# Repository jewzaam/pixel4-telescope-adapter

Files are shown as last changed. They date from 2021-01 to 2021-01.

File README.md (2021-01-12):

# Overview

This is a set of models to take pictures using a Pixel 4 phone when using an eyepiece adapter.  For example, I use a 2" to 1.25" adapter to fit 1.25" eyepieces to my 8" Dobsonian (Orion SkyQuest XT8).  This project replaces the 2" to 1.25" adapter with a tube that a custom Pixel 4 case can attach onto.

## You will need...

- access to a 3D printer
- enough plastics to print with
- 3x hex bolts of short length
- 1x hex bolt of longer length

## OpenSCAD

Some conventions I use are docuemted in my [openscad-library](https://github.com/jewzaam/openscad-library) repo along with some tools I find useful for debugging, building shapes, etc for this and other projects.  This project has no direct dependencies on other projects at this time, NO external libraries needed!!

All OpenSCAD input parameters are prefixed with `input_` and have initial values of what I used for my first full print.  For that I selected:
- short hex bolts: M4-0.7 x 10mm
- long hex bolt: M4-0.7 x 25mm
- eyepiece adapter height: 35mm
- eyepiece outer diameter: 56mm
- case adapter height: 35mm
- case inner diameter: 57mm

# Building the Adapter

## Knurled Bolts

The bolts I got are not easily turned by hand so I printed knurled caps:
- eyepiece adapter: [scad](src/knurled-hex-cap.scad), [stl](stl/m4-knurled-cap-shallow.stl), [thingieverse]()
- case adapter: [scad](src/knurled-hex-cap.scad), [stl](stl/m4-knurled-cap.stl), [thingieverse](https://www.thingiverse.com/thing:4716337)

Note on the diameter of the cap, make sure it will not be big enough to interfer with the camera adapater.  If it's too wide you can't push the camera adapter all the way down on the eyepiece adapter due to hitting the knurled cap for holding the 1.25" eyepiece.  Also you can do differenet diameters if that is what you want.  I went simple, same for everything.

I did these in a bright color I could easily see on a dark night.  If I get some glow in the dark filiment again maybe that would be better...

No support required.

A center hole punch and a hole drilled in a bit of wood were used to gently drive the bolt into the cap.

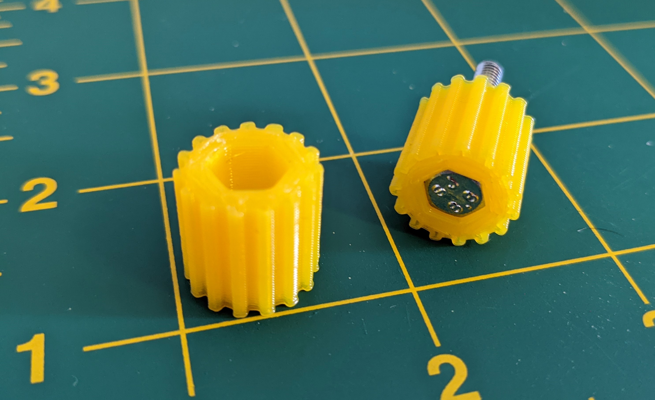
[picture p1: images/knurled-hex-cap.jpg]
Knurled Cap


## Eyepiece Adapter

A simple print that does require support.  Recommend printing in the orientation given.  You want to surface the 1.25" eyepiece rests on (inside the tube) to be smooth.  You also want the print to be tight.  You can sand it down.  This ensures you have a solid basis for the whole system.  Note there isn't anything specific to the Pixel 4 in this print!  If you have a different phone you could spend the time to create a case for it and use this adapter.

At the top of the [scad](src/telescope-eyepiece-adapter-with-extension.scad) you'll find a writeup on why I selected the values I selected.  If you're looking at your eyepieces and wondering what you need to print this may help.

Print with supports.  Select a pretty good in-fill.  I did 50% and it's solid.

After printing use your long knurled bolt to "cut" threads in the hole.

Files: [scad](src/telescope-eyepiece-adapter-with-extension.scad), [stl](stl/eyepiece-adapter-35mm.stl), [thingieverse]()

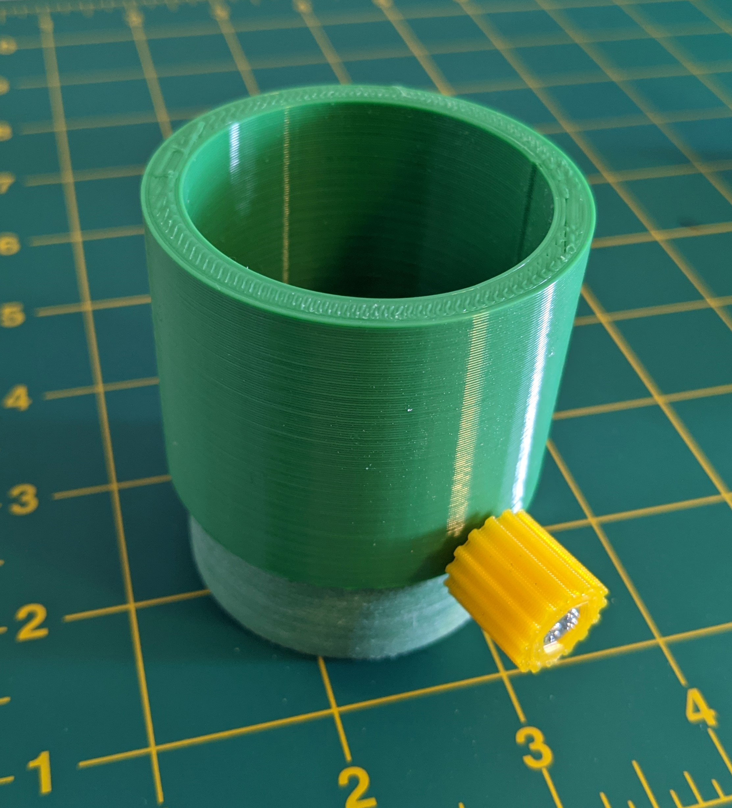
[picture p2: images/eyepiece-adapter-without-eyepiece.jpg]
Eyepiece Adapter without Eyepiece


This will be used to hold your 1.25" eyepiece in the adapter.

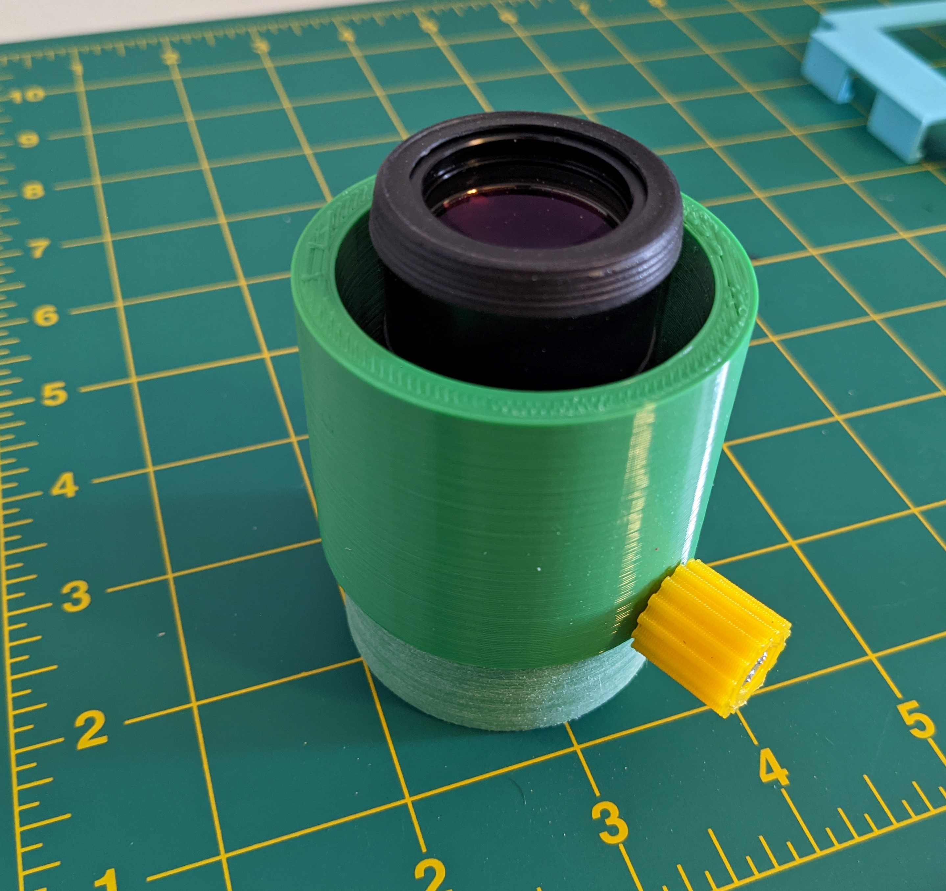
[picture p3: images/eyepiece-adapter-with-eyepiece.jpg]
Eyepiece Adapter with Eyepiece


## Pixel 4 Adapter

The phone adapter is printed attached to a phone case.  It attaches to the eyepiece adapter by screwing down 3 short bolts you created earlier.  This allows some small adjustments in where the camera.  Early prototypes tried to rely on friction of pieces only but there were two key problems.  First I found it hard to nail down the tolerances, so prints were never quite the right diameters.  Second when I did get it right the weight of the phone on the case could cause things to misalign.

Print with supports.  Select a pretty good in-fill.  I did 50% and it's solid. (Yes, this is the same as the eyepiece adapter.)

After printing use the short knurled bolst to "cut" threads in each of the 3 holes.

Files: [scad](src/pixel4-eyepiece-adapter.scad), [stl](stl/pixel4-eyepiece-adapter-35mm.stl), [thingieverse]()

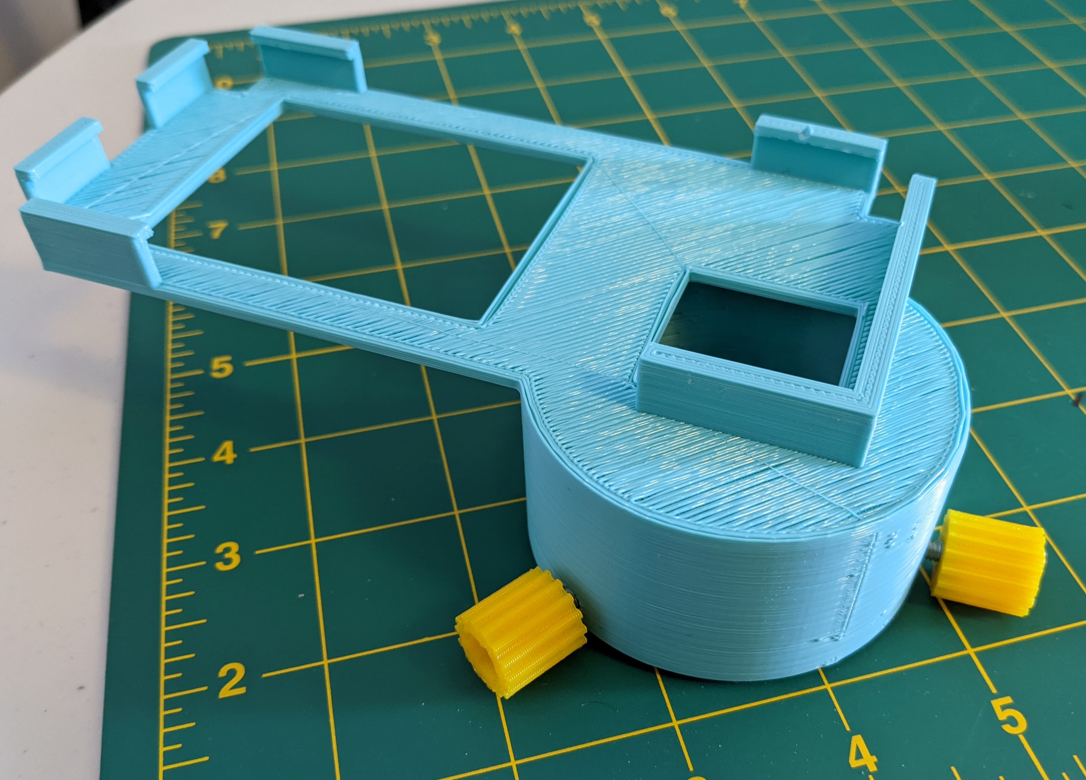
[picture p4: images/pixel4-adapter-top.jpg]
Pixel 4 Adapter, Top


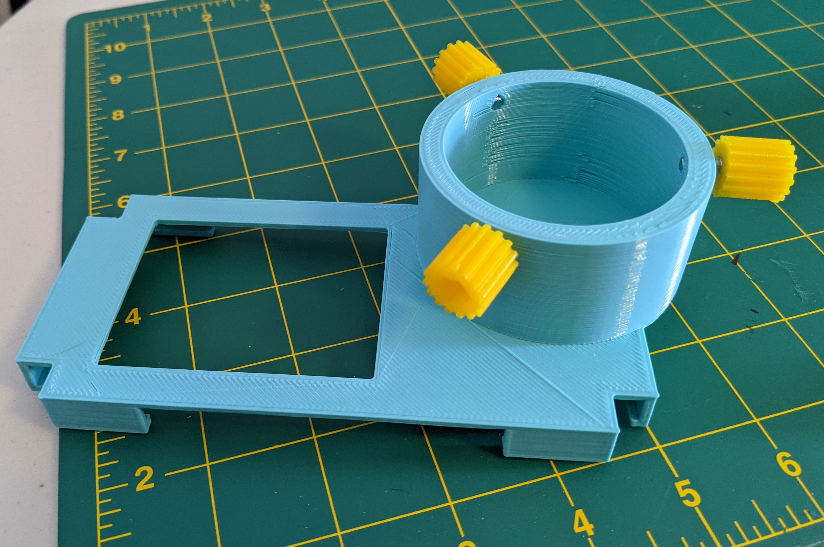
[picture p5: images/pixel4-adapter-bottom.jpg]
Pixel 4 Adapter, Bottom


# Final Results

It is really great!  After days of fiddling, test prints, and learning (aka failure) this model is rock solid.

## Install Eyepiece

The 1.25" eyepiece is placed into the eyepiece adapter.  Gently tighten the thumb screw like you'd do on a "normal" adapter.

Eyepiece in Adapter

## Put on Telescope

Install the eyepiece adapter on your scope's focuser.  You can focus now assuming you can get your eye in a good place relative to the eyepiece.

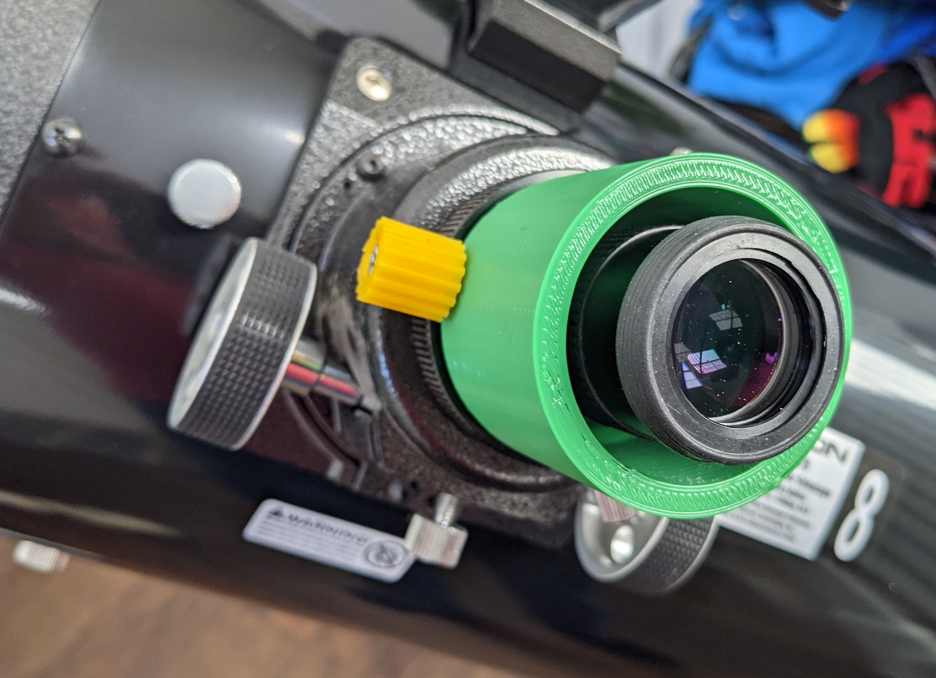
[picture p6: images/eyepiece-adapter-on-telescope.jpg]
Eyepiece on Telescope


## Install Camera

Add the camera in the case and gently tighten screws.  Turn on the camera and focus if you couldn't before or you bumped something.

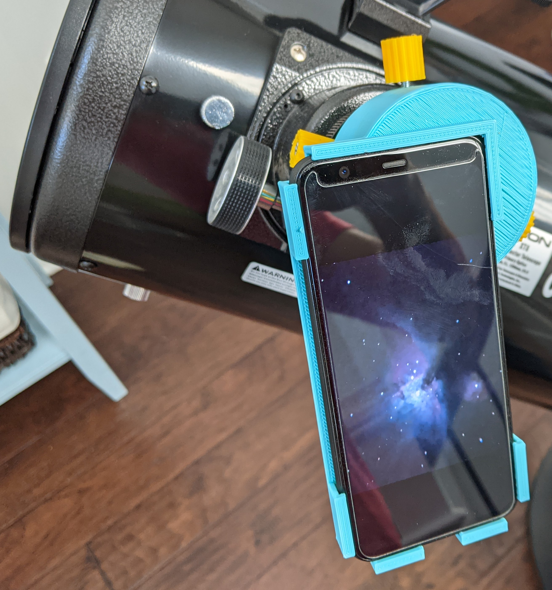
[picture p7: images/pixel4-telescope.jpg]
Pixel 4 on Telescope

(This is photo taken with a prototype of this model, yes it's inside my house, no my wall isn't M42...)

## Take Pictures!

Using my Orion SkyQuest XT7 (1200mm focal length) and a 25mm eyepiece I took this shot within city limits (yea, my driveway).  I used night sight with astrophotography turned off, 3 second delay, and locked focus (not sure it makes a difference).

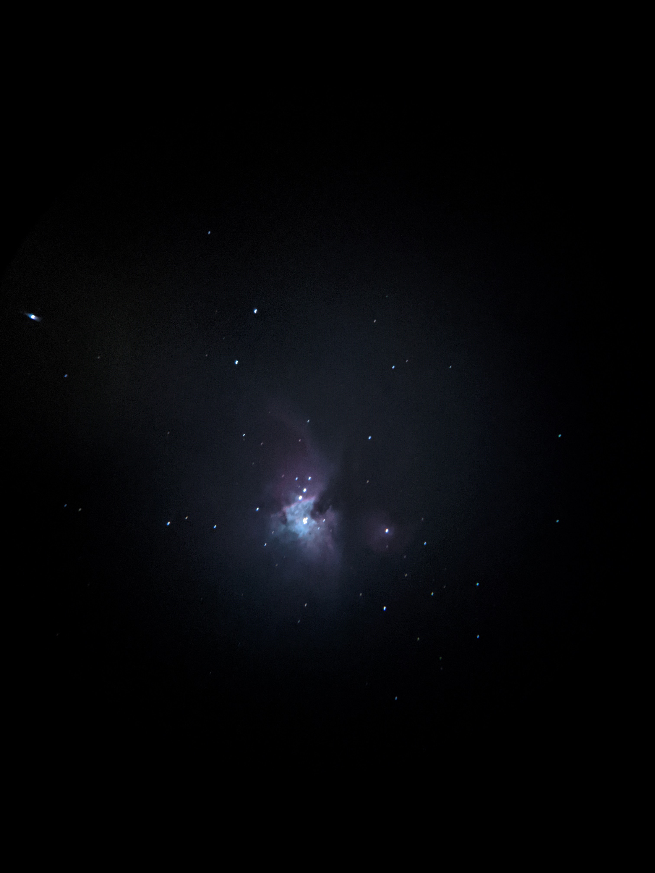
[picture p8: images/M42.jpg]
Trees


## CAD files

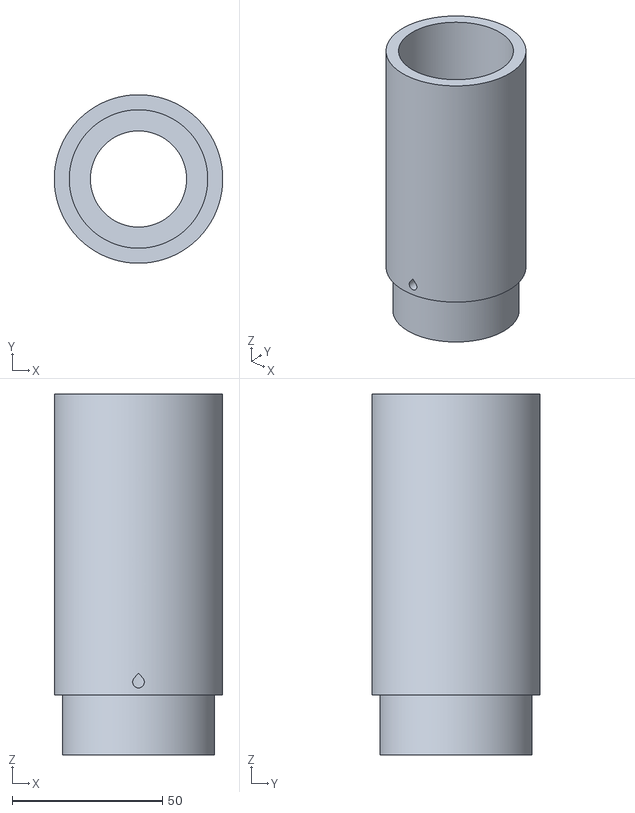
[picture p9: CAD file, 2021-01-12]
stl/eyepiece-adapter-90mm.stl
56.0 x 56.0 x 120.0

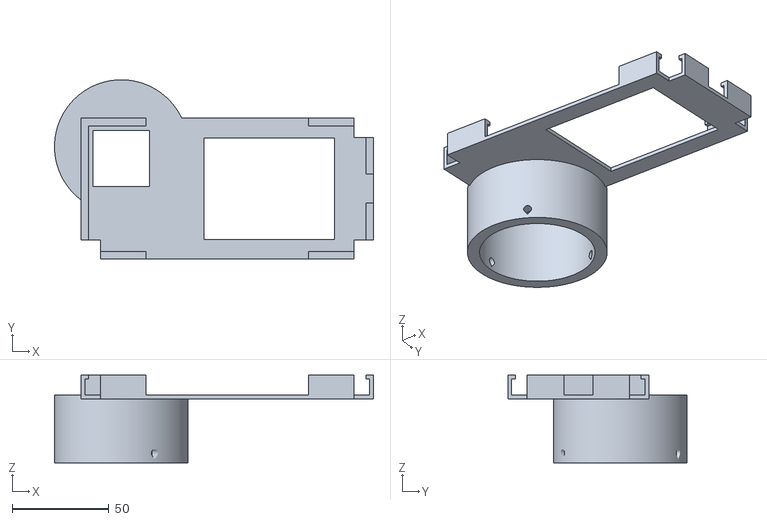
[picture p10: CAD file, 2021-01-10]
stl/pixel4-adapter-35mm.stl
164.8 x 92.6 x 45.2

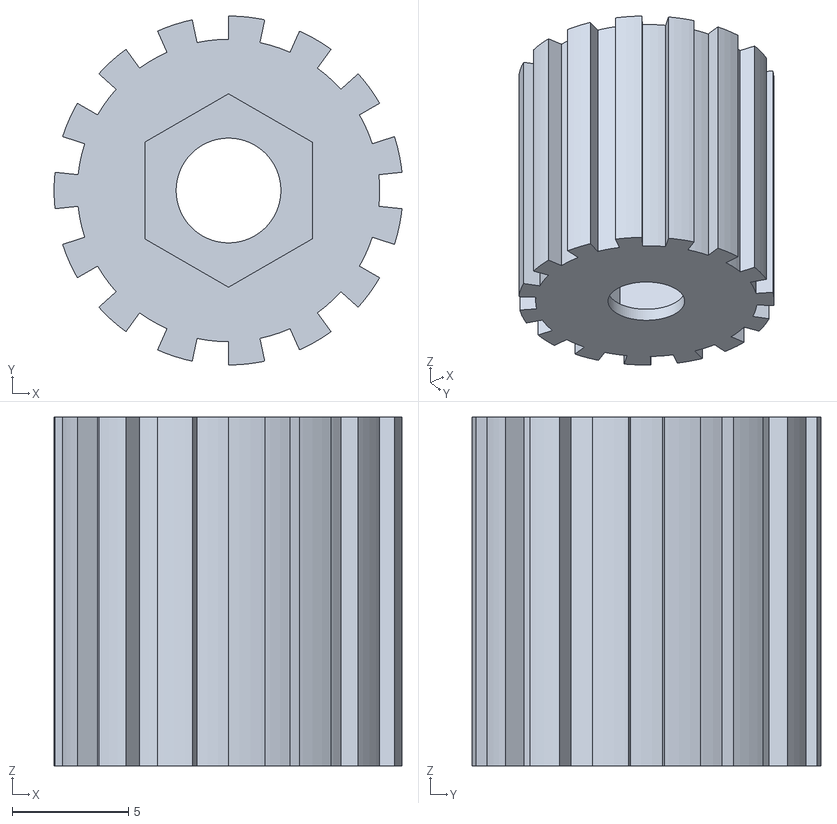
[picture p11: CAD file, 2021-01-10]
stl/m4-knurled-cap.stl
15.0 x 15.0 x 15.0

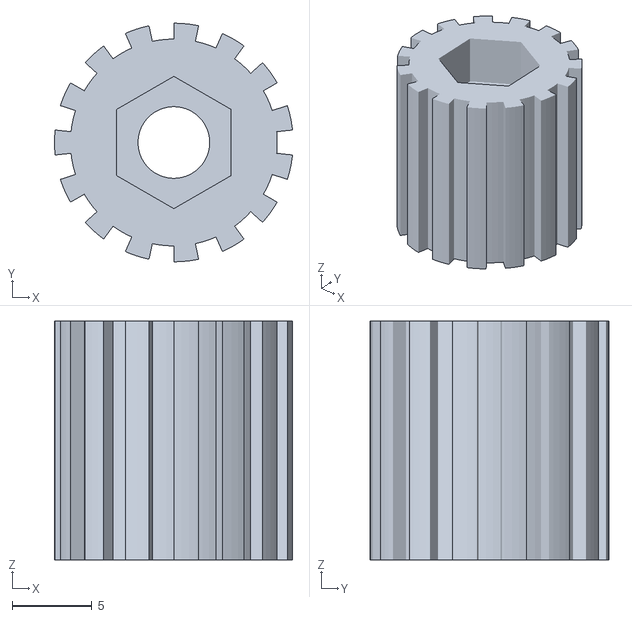
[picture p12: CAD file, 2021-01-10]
stl/m4-knurled-cap-shallow.stl
15.0 x 15.0 x 15.0

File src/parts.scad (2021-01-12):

include <library/knurled-hex-cap.scad>
include <library/eyepiece-adapter.scad>
include <library/phone-adapter.scad>

include <phones/pixel4.scad>
include <phones/iphone11.scad>

part="pixel4_case"; // [pixel4_case:Pixel 4 Case,iphone11_case:iPhone11 Case,hex_cap:Hex Caps,eyepiece_adapter:Eyepiece Adapter]

/* [General] */
// Compensate for extra surface area added by extrusion for the inner and outer diameters.  NOT USED for the lip or extension!
input_over_extrusion=0.1;

// Diameter of your screw threads.  Assumes everything uses uniform bolts though lengths can vary.
input_screw_thread_diameter=3.9;


/* [Pixel 4 Case] */

// Thickness of the case.
input_case_thickness=2;

// Width of the case lip.
input_case_lip=2;

// Adapter inner diameter (this must be wider than the eyepiece adapter outer diameter!)
input_case_adapter_inner_diameter=57;

// Adapter thickness
input_case_adapter_thickness=6;

// If this is made too high not all eyepieces can be attached.  Consider a short eyepiece.
input_case_adapter_height=35;

// Distance to put screws from bottom of adapter
input_case_adapter_screw_offset=5;

// Number of screws.
input_case_adapter_screw_count=3;

/* [Eyepiece Adapter] */

// The outer diameter (inches) of the adapter.  This is what fits into the telescope (or some larger adapter).
input_eyepiece_adapter_outer_diameter_inches=2;

// The inner diameter (inches) of the adapter, also the outer diameter of your eyepiece.
input_eyepiece_adapter_inner_diameter_inches=1.25;

// The outer diameter (inches) of the lip (with screw).  Note this is also the OD of the extension.
input_eyepiece_adapter_lip_outer_diameter=56;

// Overall height (mm) of the adapter, including the lip.  Doesn't change per eyepiece.
input_eyepiece_adapter_height=30;

// Height (mm) of just the lip.  If zero (0) no screw is added.  Doesn't change per 
input_eyepiece_adapter_lip_height=10;

// Height from top of "lip" to top of the extension.
input_eyepiece_adapter_extension_height=20;

// Height from top of "lip" to top of the extension.
input_eyepiece_adapter_extension_thickness=5;

/* [Knurled Hex Caps] */

// Outer diameter of the cap.
input_cap_outer_diameter=15;

// Height of the cap.
input_cap_height=15;

// Distance from one flat edge of hex to other.  Consider adding a bit for printer over excrusion.
input_hex_width=7.2;

// Diameter of the threaded screw.  Consider adding a bit for printer over excrusion.
input_screw_diameter=4.5;

// Amount of material the hex will rest on
input_buffer_height=1;

// Number of knurled ridges.  This also drives the width of the knurles.
input_knurl_count=15;

// Knurl depth.  Go too far and you eat through the model..
input_knurl_depth=1;

/* [Hidden] */
$fn=300;

if (part == "pixel4_case") {
    phone_adapter
    (
        phone_xyz=pixel4_phone_xyz,
        phone_dim=pixel4_phone_dim,
        phone_rot=pixel4_phone_rot,
        phone_buttons_dim=pixel4_buttons_dim,
        phone_buttons_xyz=pixel4_buttons_xyz,
        phone_buttons_rot=pixel4_buttons_rot,
        phone_camera_dim=pixel4_camera_dim,
        phone_camera_xyz=pixel4_camera_xyz,
        phone_camera_rot=pixel4_camera_rot,
        phone_camera_center_xyz=pixel4_camera_center_xyz,
        phone_power_width=pixel4_power_width,
        case_thickness=input_case_thickness,
        case_lip=input_case_lip,
        adapter_inner_diameter=input_case_adapter_inner_diameter,
        adapter_thickness=input_case_adapter_thickness,
        adapter_height=input_case_adapter_height,
        adapter_screw_offset=input_case_adapter_screw_offset,
        adapter_screw_count=input_case_adapter_screw_count,
        adapter_screw_diameter=input_screw_thread_diameter
    );
} else if (part == "iphone11_case") {
    phone_adapter
    (
        phone_xyz=iphone11_phone_xyz,
        phone_dim=iphone11_phone_dim,
        phone_rot=iphone11_phone_rot,
        phone_buttons_dim=iphone11_buttons_dim,
        phone_buttons_xyz=iphone11_buttons_xyz,
        phone_buttons_rot=iphone11_buttons_rot,
        phone_camera_dim=iphone11_camera_dim,
        phone_camera_xyz=iphone11_camera_xyz,
        phone_camera_rot=iphone11_camera_rot,
        phone_camera_center_xyz=iphone11_camera_center_xyz,
        phone_power_width=iphone11_power_width,
        case_thickness=input_case_thickness,
        case_lip=input_case_lip,
        adapter_inner_diameter=input_case_adapter_inner_diameter,
        adapter_thickness=input_case_adapter_thickness,
        adapter_height=input_case_adapter_height,
        adapter_screw_offset=input_case_adapter_screw_offset,
        adapter_screw_count=input_case_adapter_screw_count,
        adapter_screw_diameter=input_screw_thread_diameter
    );
} else if (part == "hex_cap") {
    knurled_hex_cap(
        cap_od=input_cap_outer_diameter,
        cap_h=input_cap_height,
        hex_w=input_hex_width,
        screw_d=input_screw_diameter,
        buffer_h=input_buffer_height,
        knurl_count=input_knurl_count,
        knurl_depth=input_knurl_depth
    );
} else if (part == "eyepiece_adapter") {
    eyepiece_adapter(
        over_extrusion=input_over_extrusion,
        outer_diameter_inches=input_eyepiece_adapter_outer_diameter_inches,
        inner_diameter_inches=input_eyepiece_adapter_inner_diameter_inches,
        lip_outer_diameter=input_eyepiece_adapter_lip_outer_diameter,
        adapter_height=input_eyepiece_adapter_height,
        adapter_lip_height=input_eyepiece_adapter_lip_height,
        screw_thread_diameter=input_screw_thread_diameter,
        extension_height=input_eyepiece_adapter_extension_height,
        extension_thickness=input_eyepiece_adapter_extension_thickness
    );
}

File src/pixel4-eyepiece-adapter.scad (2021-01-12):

include <shapes.scad>

/*

Pixel 4 case that mounts on a custom 2" to 1.25" adapter.

https://store.google.com/us/product/pixel_4

*/

/* [Case] */

input_case_thickness=2;
input_case_lip=2;

// width of cutout for power cord
input_case_power_width=15;

/* [Case Adapter] */

// Measured diameter is 50mm but it's a very tight fit.  Make it a little wider.
input_adapter_inner_diameter=57;
input_adapter_thickness=6;

// If this is made too high not all eyepieces can be attached.  Consider a short eyepiece.
input_adapter_height=35;

// Distance to put screws from bottom of adapter
input_adapter_screw_offset=5;

// if printing as though phone were on its face set this to 'true'.
input_adapter_screw_invert=true;

// Number of screws.
input_adapter_screw_count=3;

/* [Hidden] */

$fn=300;

i_x=0;
i_y=1;
i_z=2;
i_h=0;  // height
i_id=1; // inner diameter
i_od=2; // outer diameter

ORIGIN=[0,0,0];

// so I have a named variable and not burried in other places
const_camera_offset_y=6.31;

phone_xyz=[0,0,0];
phone_dim=[147.13,68.8,8.24];
phone_rot=[0,0,0];

case_xyz=[phone_xyz[i_x]-input_case_thickness,phone_xyz[i_y]-input_case_thickness,phone_xyz[i_z]-input_case_thickness];
case_dim=[phone_dim[i_x]+input_case_thickness*2,phone_dim[i_y]+input_case_thickness*2,phone_dim[i_z]+input_case_thickness*2];
case_rot=phone_rot;

camera_dim=[25,25,1];
camera_xyz=[phone_xyz[i_x]+6.35,phone_xyz[i_y]+phone_dim[i_y]-camera_dim[i_y]-6.35,-1];
camera_rot=phone_rot;

// simply cut off anything above the buttons
buttons_dim=[40,0.5,2.8];
buttons_xyz=phone_xyz+[33.5,phone_dim[i_y],2.6];
buttons_rot=phone_rot;

adapter_cyl=[input_adapter_height,input_adapter_inner_diameter,input_adapter_inner_diameter+input_adapter_thickness*2];
adapter_rot=ORIGIN;

// the adapter model is centered at ORIGIN, so needs z translation
// line up z with bottom of the phone, not camera
camera_center_xyz=camera_xyz+[camera_dim[i_x]/2,camera_dim[i_y]-const_camera_offset_y,-adapter_cyl[i_h]/2-camera_xyz[i_z]];

adapter_xyz=camera_center_xyz;

// cut material based on existing dimensions, reduces print time etc

// constant for corner cuts
const_corner_cut_h=10;

material_dim=phone_dim-[
    camera_center_xyz[i_x]+adapter_cyl[i_od]/2+phone_dim[i_z]*2+ const_corner_cut_h,
    phone_dim[i_z]*2,
    0
];

material_xyz=phone_xyz+[
    camera_center_xyz[i_x]+adapter_cyl[i_od]/2+phone_dim[i_z],
    phone_dim[i_z],
    case_xyz[i_z]-1 // we're using this to cut, this ensure it's clean
];
material_rot=case_rot;

// Make multiple cuts for the case.
// By index:
// 0 - main phone body
// 1 - phone screen area
// 2 - camera
// 3 - sides
// 4 - material reduction
// 5 - corner, top left
// 6 - corner, bottom left
// 7 - corner, bottom right
// 8 - power
case_cut_count=9;
case_cuts_xyz=[
    // phone body
    phone_xyz,
    // phone screen
    [phone_xyz[i_x]+input_case_lip,phone_xyz[i_y]+input_case_lip,phone_xyz[i_z]],
    // phone camera
    [camera_xyz[i_x]-input_case_thickness,camera_xyz[i_y]-input_case_thickness,camera_xyz[i_z]-input_case_thickness*.51],
    // case sides (based on buttons)
    [buttons_xyz[i_x]-input_case_thickness,case_xyz[i_y]-input_case_thickness,0],
    // remove material
    material_xyz,
    // corner, top left
    case_xyz-[const_corner_cut_h,const_corner_cut_h,case_dim[i_z]/2],
    // corner, bottom left
    case_xyz+case_dim-[const_corner_cut_h,const_corner_cut_h+case_dim[i_y],case_dim[i_z]*3/2],
    // corner, bottom right
    case_xyz+case_dim-[const_corner_cut_h,const_corner_cut_h,case_dim[i_z]*3/2],
    // power
    case_xyz+[case_dim[i_x]-input_case_thickness*3,case_dim[i_y]/2-input_case_power_width/2,input_case_thickness]
];
case_cuts_dim=[
    // phone body
    phone_dim,
    // phone screen
    [phone_dim[i_x]-input_case_lip*2,phone_dim[i_y]-input_case_lip*2,case_dim[i_z]*2],
    // phone camera
    [camera_dim[i_x]+input_case_thickness*2,camera_dim[i_y]+input_case_thickness*2,input_case_thickness*2],
    // case sides (based on buttons)
    [phone_dim[i_x]-2*(buttons_xyz[i_x]-phone_xyz[i_x])+input_case_thickness*2,case_dim[i_y]+input_case_thickness*2,phone_dim[i_z]+input_case_thickness*2],
    // remove material
    material_dim,
    // corner, top left
    [const_corner_cut_h*2,const_corner_cut_h*2,case_dim[i_z]*2],
    // corner, bottom left
    [const_corner_cut_h*2,const_corner_cut_h*2,case_dim[i_z]*2],
    // corner, bottom right
    [const_corner_cut_h*2,const_corner_cut_h*2,case_dim[i_z]*2],
    // power
    [input_case_thickness*6,input_case_power_width,phone_dim[i_z]+input_case_thickness*2]
];
case_cuts_rot=[
    // phone body
    phone_rot,
    // phone screen
    case_rot,
    // phone camera,
    case_rot,
    // case sides (based on buttons)
    case_rot,
    // remove material
    material_rot,
    // corner, top left
    ORIGIN,
    // corner, botom left
    ORIGIN,
    // corner, bottom right
    ORIGIN,
    // power
    ORIGIN
];

module adapter(c="purple",t=1) 
{
    color(c,t)
    difference()
    {
        // main body
        tube(xyz=adapter_xyz,cyl=adapter_cyl,rot=adapter_rot,top_h=input_case_thickness);
        
        // cut: mirror area only (do not cut anything else)
        case_cuts([2]);
        
        // cut: screw holes
        a=360/input_adapter_screw_count;
        translate(adapter_xyz)
        for (i=[0:input_adapter_screw_count]) {
            rotate([0,0,i*a+(input_adapter_screw_invert?a/2:0)])
            translate([0,0,-input_adapter_height/2+input_adapter_screw_offset])
            rotate([0,input_adapter_screw_invert?90:-90,0])
            screw_hole(d=input_adapter_screw_diameter,h=input_adapter_inner_diameter*2);
        }
    }
}

module phone(t=1) 
{
    box(phone_xyz,phone_dim,phone_rot,"lightblue",t);
    box(camera_xyz,camera_dim,camera_rot,"purple",t);
    box(buttons_xyz,buttons_dim,buttons_rot,"purple",t);
}

module case_cuts(cut_array=[0:case_cut_count-1]) 
{
    for (i=cut_array) {
        cut_xyz=case_cuts_xyz[i];
        cut_rot=case_cuts_rot[i];
        cut_dim=case_cuts_dim[i];
        
        translate(cut_xyz)
        rotate(cut_rot)
        cube(cut_dim);
    }
}

module case(xyz=case_xyz,dim=case_dim,rot=case_rot,c="lime",t=1,fancy=true) 
{
    // the sphere params
    s_d=fancy?input_case_thickness:0;
    
    color(c,t)
    difference()
    {
        // case body made from the base dimensions but w/ minkowski of a sphere
        minkowski()
        {
            translate(xyz+[s_d/2,s_d/2,s_d/2])
            rotate(rot)
            cube(dim-[s_d/2,s_d/2,s_d]);
            
            if (fancy) {
                // put the sphere on the sides
                translate([0,xyz[i_y]+s_d/2,0])
                sphere(d=s_d);
            }
        }

        // make the cuts
        case_cuts();
    }
}

union() {
    adapter();
    case(fancy=false);
}

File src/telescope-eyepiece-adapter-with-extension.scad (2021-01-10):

/*

The "lip" is where the eyepiece sits.  Take the height of your EP and add the eye relief.  This is probably about where you want your camera.  But maybe not!  You cannot have the camera go _into_ the EP.  The minimum height should be your EP height from the lip.  Add more depending on the camera adapter height.

Let's look at an example.  Let's say your EP is 45mm high from the lip.  And let's say the eye relief for the EP is 15mm.  Furthermore, your camera adapter height is 30mm with screws at 10mm, so effectively about 20mm.  In this case you need your camera to be 15mm above the EP.  If the camera adapter is fully over the extension to get 15mm away from the EP means the extension is 15mm above the top of the EP.  You then have 20mm of play with the camera adapter.  You probably want some play that goes below the eye relief, I'd guess 5mm.  Therefore my recommended extension height is 45mm + 15mm - 5mm = 55mm.

With this setup you have to have many eyepiece adapters for different eyepieces because of EP height and ideal viewing distance (eye relief).  For the eyepieces you want to use do the math to figure out the extension height and print along 5mm spacing.  Therefore you're close enough if another eyepiece (borrowed, new, etc) is close to an existing eyepiece height.  And you're not printing one adapter per eyepiece.

This setup is for my shortest eyepiece, Celestron Omni 9mm Plossl.  Eyepiece height is 17mm.  Eye relief per Celestron is 6mm.  Super short at 23mm!  I selected 20mm and will have to make sure my camera adapter is probably 20mm too.  And place the screws as close to the lower edge as I can to get more flexibility.

I also have to think about my biggest eyepiece at this time, Celestron Omni 40mm Plossl.  The phone case will be printed with the lip OD, so getting it right on ALL the adapters means fewer phone cases, hopefully one!  The outer diameter of this eyepiece is 42mm.  With the extension thickness set to 5mm (beefy, but I don't want it to move) I can do a minimum lip OD of 47mm.  My stock 2" to 1.25" adapter is 2.2in (55.88mm).  So I am rounding up to 56 and having enough room for an even bigger EP if I want.  Yay flexibility!

NOTE in this model you change only the "Eyepiece / Camera Adapter" values per eyepiece.

*/

/* [2" to 1.25" Adapter] */

// Compensate for extra surface area added by extrusion for the inner and outer diameters.  NOT USED for the lip or extension!
input_over_extrusion=0.1;

// The outer diameter (inches) of the adapter.  This is what fits into the telescope (or some larger adapter).
input_outer_diameter_inches=2;

// The inner diameter (inches) of the adapter, also the outer diameter of your eyepiece.
input_inner_diameter_inches=1.25;

// The outer diameter (inches) of the lip (with screw).  Note this is also the OD of the extension.
input_lip_outer_diameter=56;

// Overall height (mm) of the adapter, including the lip.  Doesn't change per eyepiece.
input_adapter_height=30;

// Height (mm) of just the lip.  If zero (0) no screw is added.  Doesn't change per 
input_adapter_lip_height=10;

// Diameter of your screw threads.
input_screw_thread_diameter=3.91;

/* [Eyepiece / Camera Adapter] */
// Height from top of "lip" to top of the extension.
input_extension_height=20;

// Height from top of "lip" to top of the extension.
input_extension_thickness=5;

// Make it printable without support by having the extension 
/* [Hidden] */
$fn=300;

// raw shape for the adapter (hidden: standard sizes)
adapter_2125_h=input_adapter_height;
adapter_2125_id=input_inner_diameter_inches*25.4+input_over_extrusion*2;
adapter_2125_od=input_outer_diameter_inches*25.4-input_over_extrusion*2;
adapter_2125_lip_h=input_adapter_lip_height;
adapter_2125_lip_od=input_lip_outer_diameter;

adapter_2125_screw_thread_d=input_screw_thread_diameter;

// offset from lip top (hidden: standard location for screw into eyepiece)
adapter_2125_screw_offset_from_lip_top_z=3.8;

module adapter() {
    // built upside down, fip for printing.  -90 on Z is for thingieverse orientation
    rotate([0,0,-90])
    difference() 
    {
        rotate_extrude()
        union() 
        {
            // main adapter bit
            translate([adapter_2125_id/2,0,0])
            square([adapter_2125_od/2-adapter_2125_id/2,adapter_2125_h]);
            
            // lip so it doesn't fall in scope
            translate([adapter_2125_id/2,adapter_2125_h-adapter_2125_lip_h,0])
            square([adapter_2125_lip_od/2-adapter_2125_id/2,adapter_2125_lip_h]);
            
            // extension
            translate([adapter_2125_lip_od/2-input_extension_thickness,input_adapter_height,0])
            square([input_extension_thickness,input_extension_height]);
        }
        
        if (input_adapter_lip_height > 0) {
            // cut hole (extruded teardrop, easier print) for screw
            translate([0,0,-adapter_2125_screw_thread_d/2+adapter_2125_h-adapter_2125_screw_offset_from_lip_top_z])
            rotate([0,90,0]) // rotate on side
            rotate([0,0,180]) // flip teardrop over
            linear_extrude(adapter_2125_lip_od)
            hull()
            {
                circle(d=adapter_2125_screw_thread_d);
                translate([adapter_2125_screw_thread_d*0.75,0,0])
                circle(d=0.1);
            }
        }
    }
}

// Made it a module to make turning it off for debugging easy.
adapter();

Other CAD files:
src/phones/iphone11.scad
src/phones/pixel4.scad

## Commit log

2021-01-10 Initial content
    [eyepiece-adapter-35mm.stl, knurled-hex-cap.scad, m4-knurled-cap-shallow.stl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]
2021-01-10 Docs updates and scad tweaks
    Removed unused scad bits and moved to openscad-library repository
    [pixel4-eyepiece-adapter.scad]
2021-01-12 Restructured
    Trying to make it easier to extend by breaking apart into separate files that are imported, including a separate file for phone variables. A single `parts.scad` now generates all the parts.
    [eyepiece-adapter-90mm.stl, knurled-hex-cap.scad, parts.scad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]
2021-01-12 Fixed broken include
    [parts.scad]
2021-01-12 Stubbed out iPhone11 case data
    And moved the phone variables into `src/phones/<phoneName>.scad`
    [iphone11.scad, parts.scad, pixel4.scad]
